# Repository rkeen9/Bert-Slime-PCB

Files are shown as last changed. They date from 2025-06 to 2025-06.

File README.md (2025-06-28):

# Bert-Slime-Tracker
**DOES NOT WORK YET.** If you build this, you will get a non-functional tracker. This repository will be updated once troubleshooting is complete. I'm documenting the troubleshooting here: [Troubleshooting](https://github.com/rkeen9/Bert-Slime-Tracker/blob/main/Troubleshooting/Troubleshooting.md)

Another slime tracker. This one was designed for small form factor and easy DIY that involves minimal soldering and easily obtainable parts. This is essentially just an ICM-45686 breakout board which you can install a D1 mini directly to via 2x8 port 2.54 mm female headers. A TP-4056 charger module can also be installed directly to the board via 2.54mm male headers. Assembly instructions to come once this project is functional.

# Folder Structure 
- **Bert-Slime-Tracker/** Main folder. Contains KiCAD project files and all other folders.
- **Bert-Slime-Tracker/Libraries** Contains all custom symbols and footprints used in this project
- **Bert-Slime-Tracker/assembly-files** Contains all files that would be needed to have this project built by JLCPCB (https://jlcpcb.com/).
- **Bert-Slime-Tracker/Schematics** Contains the schematic in PDF form.
- **Bert-Slime-Tracker/Troubleshooting** Contains my efforts to get this project functional :).

# KiCAD Environment Setup
This project was made in KiCAD 9.0. KiCAD is free PCB design software which can be downloaded from https://www.kicad.org/download/. If you are familiar with KiCAD and Github, all you need to know is that the required files for all custom components are in the **Libraries** folder.

If you're new to KiCAD or need a refresher, the following is step by step instructions for opening this project following a fresh KiCAD install:
1. Download this project through GitHub's **Download Zip** option as shown below and extract it to the desired project location:
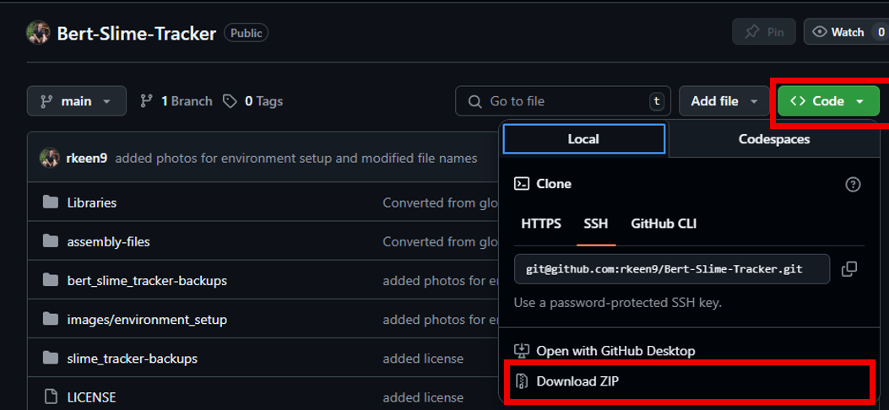
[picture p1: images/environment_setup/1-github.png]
github

2. Run KiCAD and open the **Footprint Editor** from the start screen
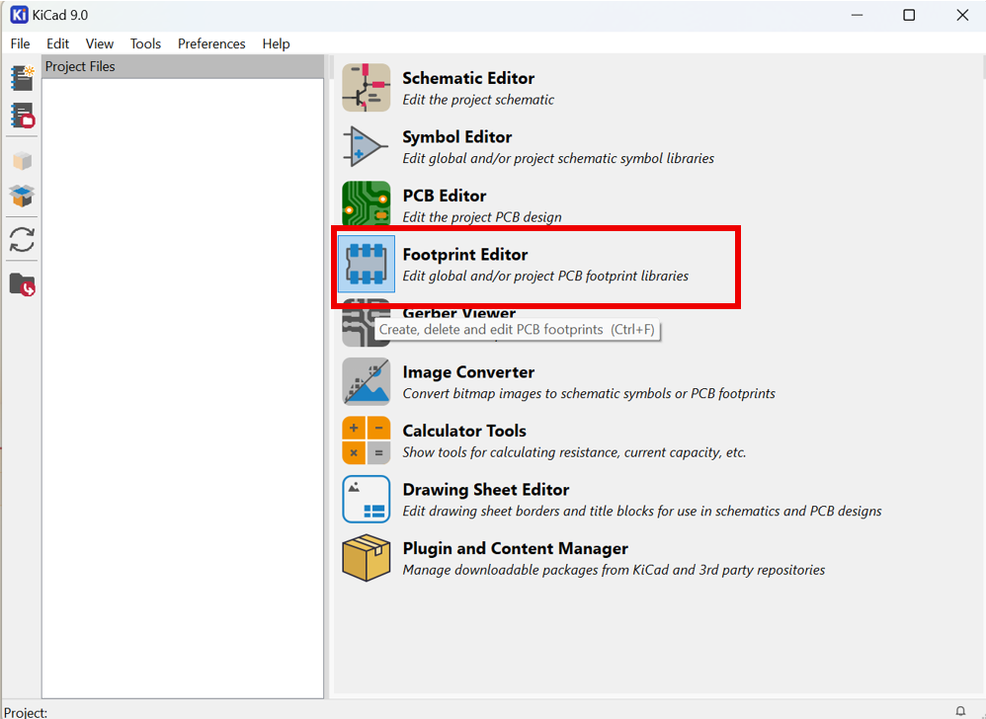
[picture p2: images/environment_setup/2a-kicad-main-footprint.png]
Main Screen

Continue with the default options if this popup appears:
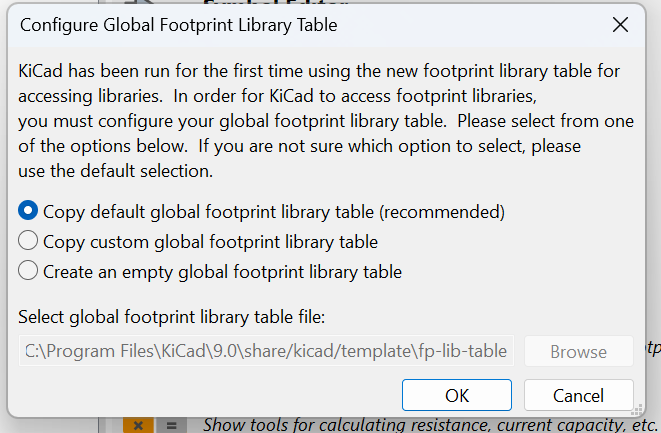
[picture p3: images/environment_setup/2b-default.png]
default

3. From the **Footprint Editor**, Go to **File>Add Library**

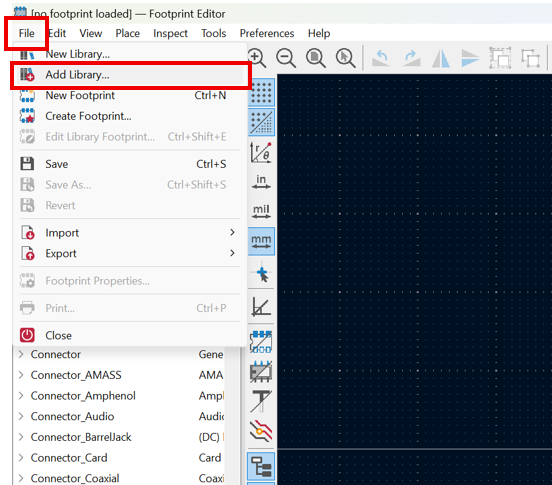
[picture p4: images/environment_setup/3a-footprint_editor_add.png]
footprint


Navigate to where you extracted the project files, select the **Libraries/Bert-Slime-PCB.pretty** folder, and hit **Select Folder**
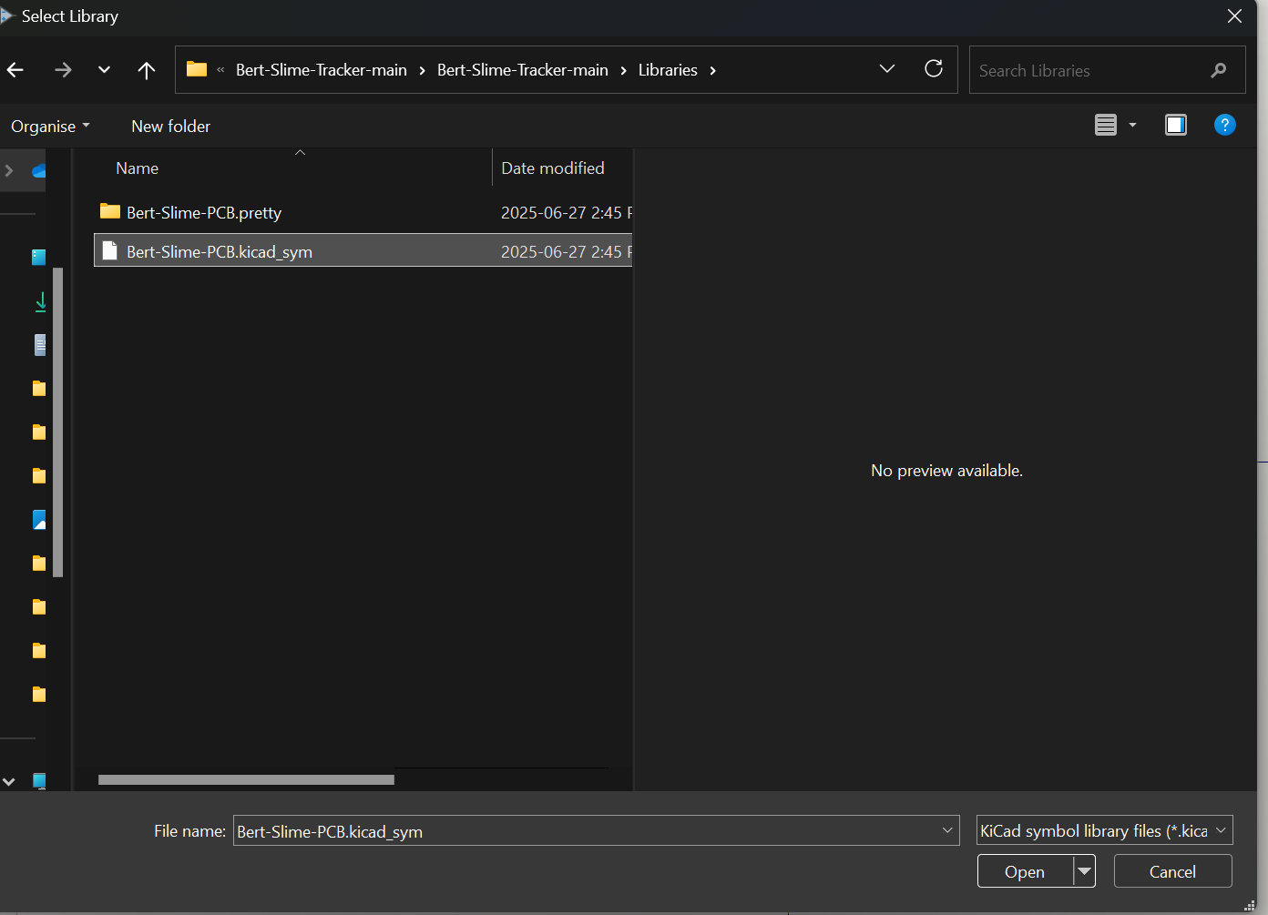
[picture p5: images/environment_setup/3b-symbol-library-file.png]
pretty file


4. Exit from the **Footprint Editor** and open the **Symbol Editor** from the KiCAD start screen
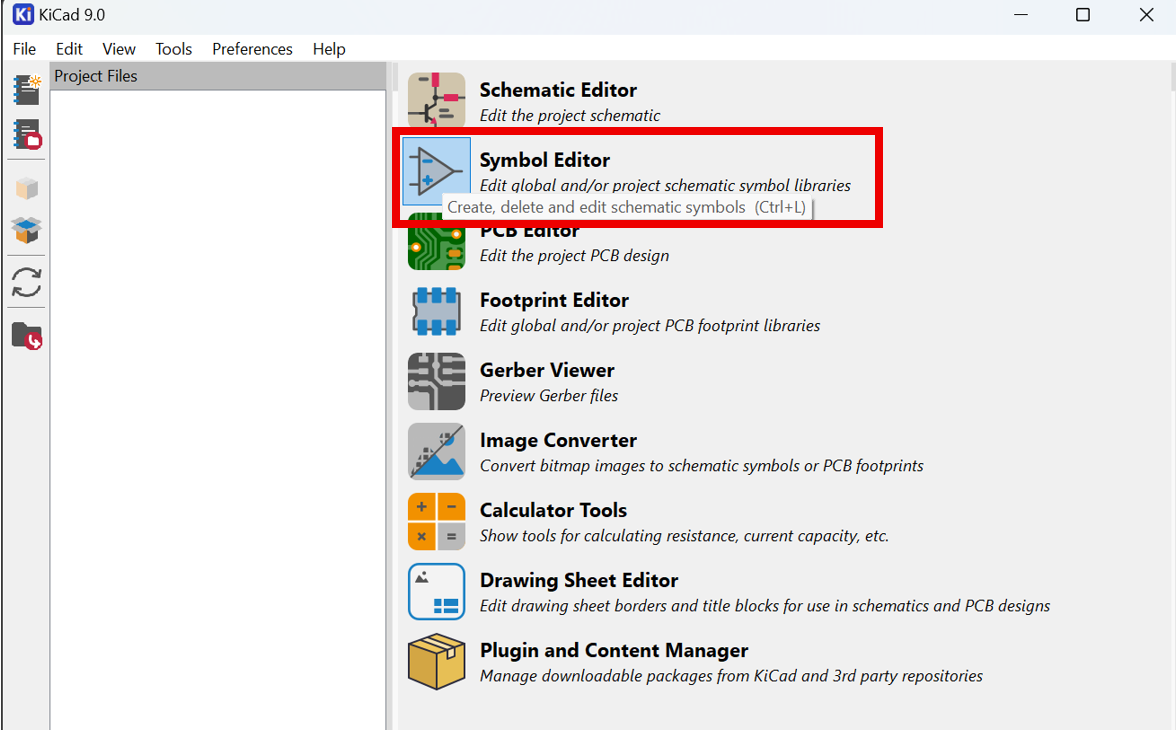
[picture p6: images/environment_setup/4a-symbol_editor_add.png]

Continue with the default options if this popup appears:
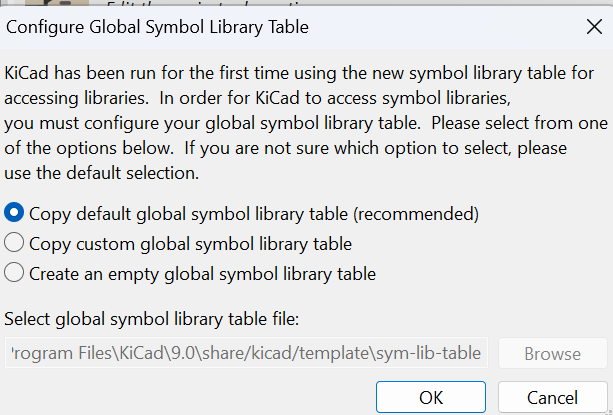
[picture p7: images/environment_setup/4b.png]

5. From the **Symbol Editor**, Go to **File>Add Library**
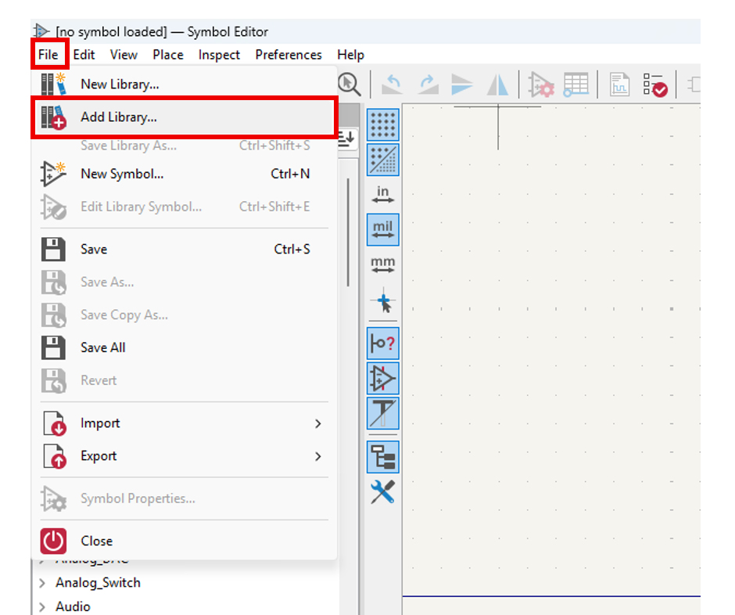
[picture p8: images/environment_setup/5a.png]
Symbol


Navigate to where you extracted the project files and open the **Libraries/Bert-Slime-PCB.kicad_sym** file.
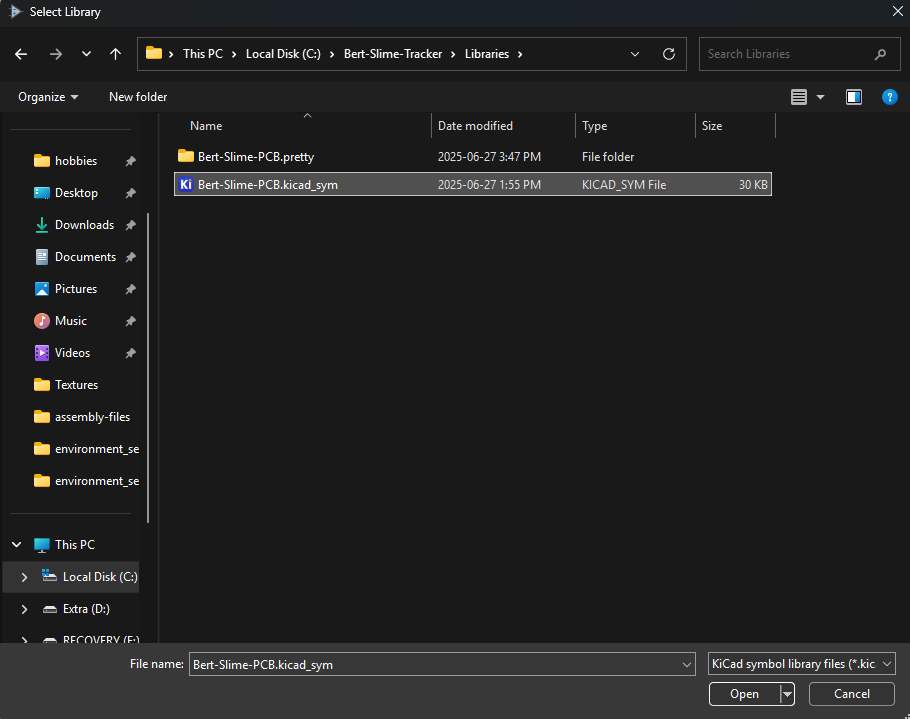
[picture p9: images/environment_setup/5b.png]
Symbol Path


6. Exit from the **Symbol Editor** and open the project from the KiCAD start screen as shown:
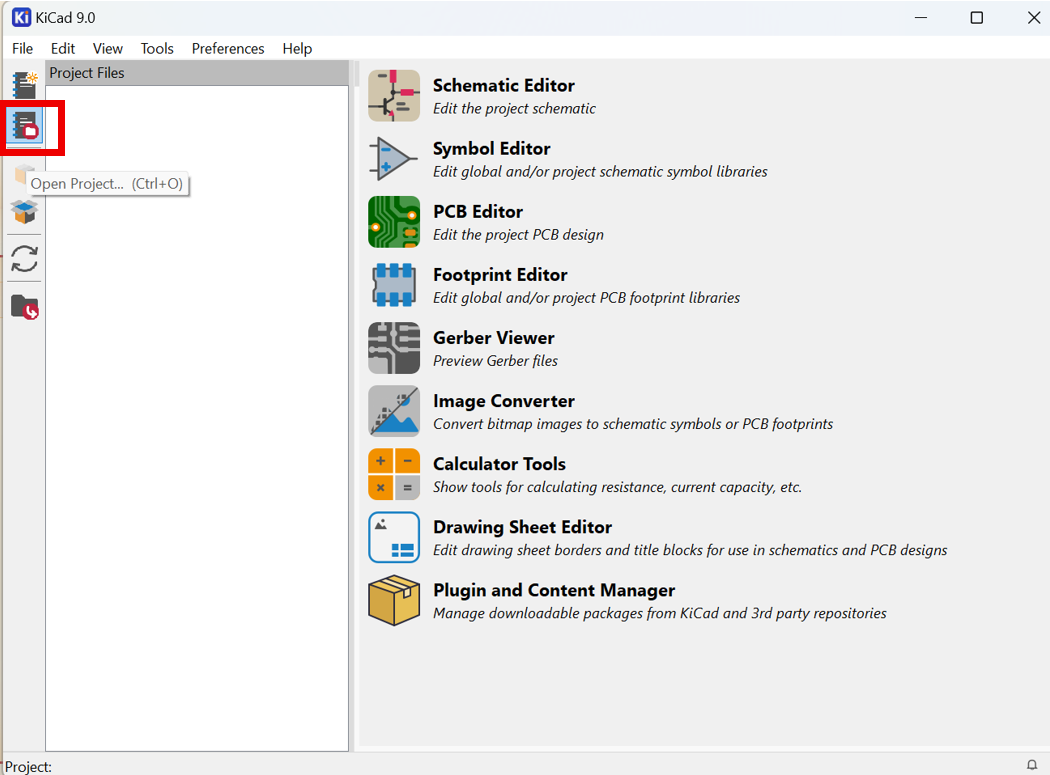
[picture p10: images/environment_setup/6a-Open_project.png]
Open Proj


Now navigate to the project folder and open the **bert_slime_tracker.kicad_pro** file
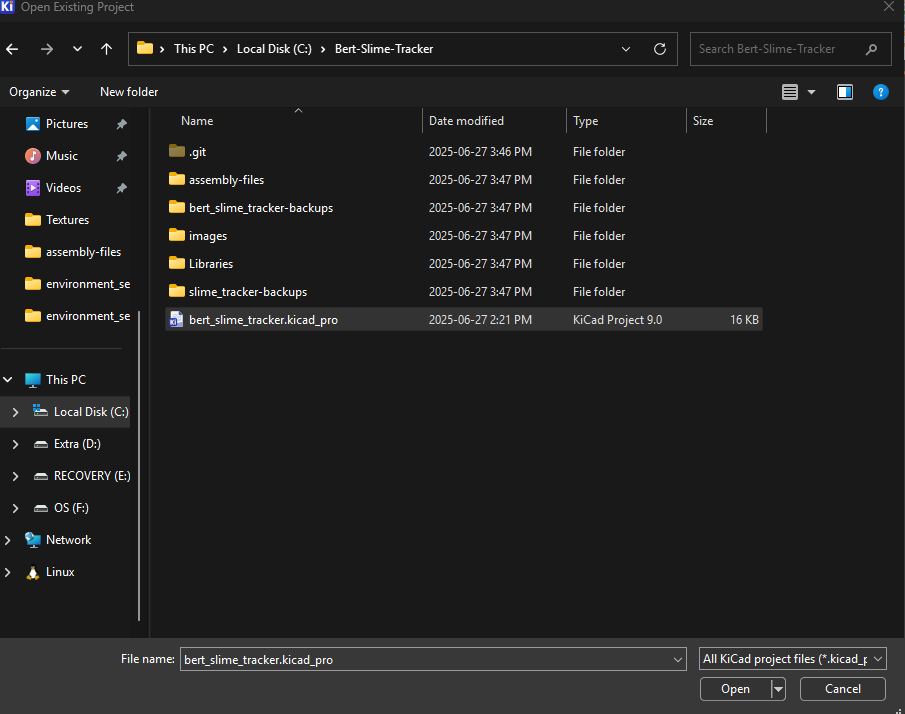
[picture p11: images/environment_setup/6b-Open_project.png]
Open Proj


7. The project can now be edited in KiCAD. the **bert_slime_tracker.kicad_sch** file contains the project schematics and the **slime_tracker.kicad_pcb** file contains the PCB design itself.

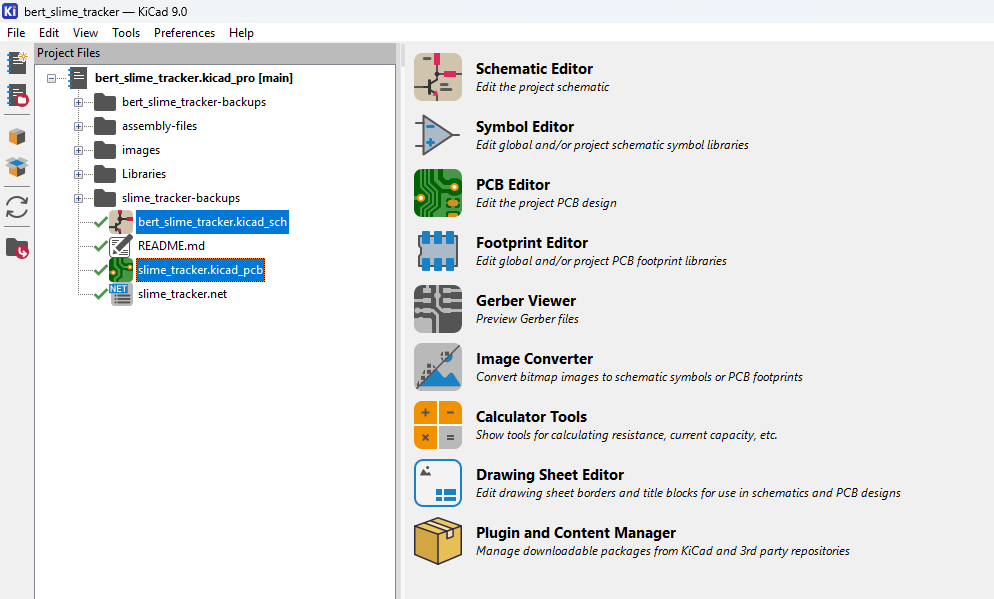
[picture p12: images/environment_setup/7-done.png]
done


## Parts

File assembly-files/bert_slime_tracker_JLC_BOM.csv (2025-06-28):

Designator | JCLPCB Part # | Footprint | Comment
C1,C2 | C1591 | Capacitor_SMD:C_0603_1608Metric | 100nF
C3 | C57895 | Capacitor_SMD:C_0603_1608Metric | 2.2uF
CN1 | C136657 | Bert-Slime-PCB:CONN-SMD_SM05B-SRSS-TB-LF-SN | SM05B-SRSS-TB (LF)(SN)
D1,D2 | C458181 | Bert-Slime-PCB:SOD993_L1.0-W0.6-LS1.0-RD | PMEG3010ESBYL
R1 | C22827 | Resistor_SMD:R_0603_1608Metric_Pad0.98x0.95mm_HandSolder | 180K
R2,R3,R4,R5 | C25804 | Resistor_SMD:R_0603_1608Metric_Pad0.98x0.95mm_HandSolder | 10K
SW1 | C963206 | Bert-Slime-PCB:SW-SMD_MK-12C02-G020 | MK-12C02-G020
U1 | C22459454 | Bert-Slime-PCB:IC_ICM-45686 | ICM-45686
U2 | C5439871 | Bert-Slime-PCB:X1-WLB0808-4_L0.8-W0.8-P0.40-TL | QMC6309
Y1 | C555607 | Crystal:Crystal_SMD_3225-4Pin_3.2x2.5mm | 32.768 kHz Oscillator

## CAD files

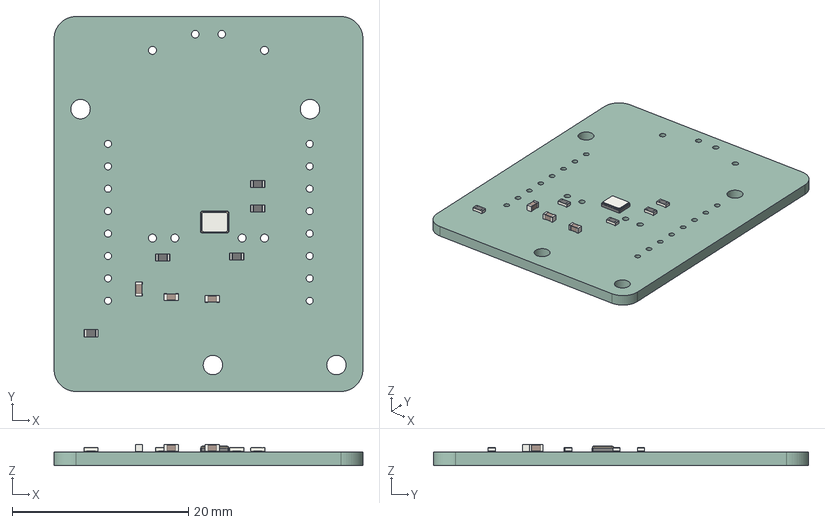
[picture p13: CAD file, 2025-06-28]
bert_slime_tracker.step
35.0 x 42.5 x 2.40 mm
R_0603_1608Metric x 5
C_0603_1608Metric x 3
Crystal_SMD_3225-4Pin_3.2x2.5mm
bert_slime_tracker_PCB

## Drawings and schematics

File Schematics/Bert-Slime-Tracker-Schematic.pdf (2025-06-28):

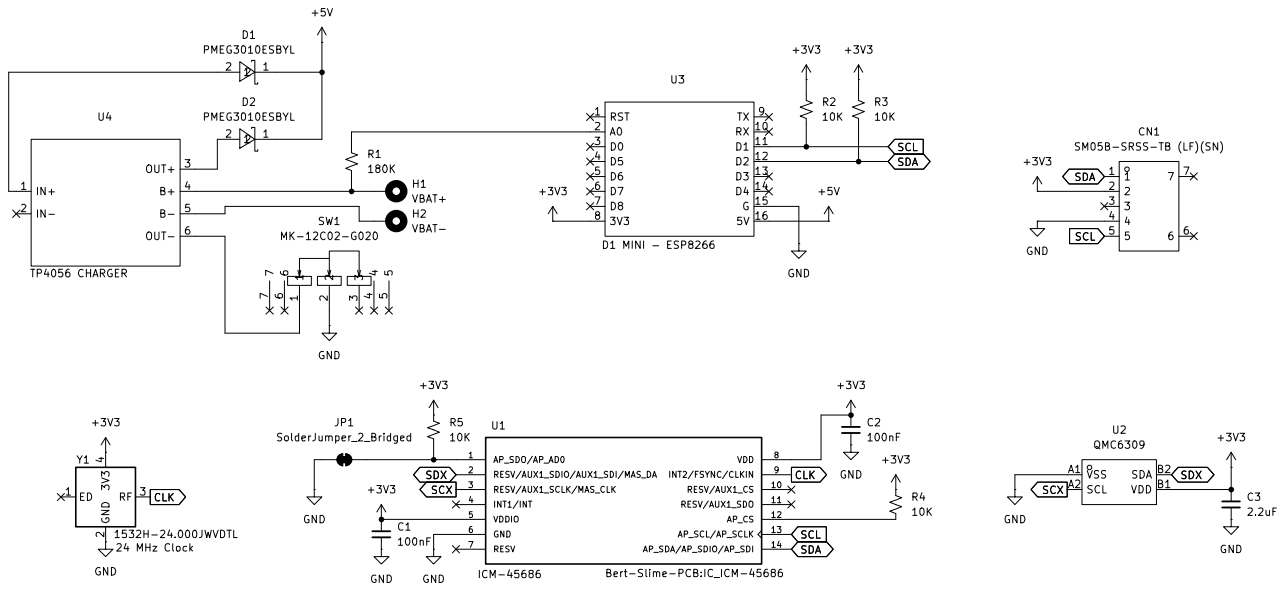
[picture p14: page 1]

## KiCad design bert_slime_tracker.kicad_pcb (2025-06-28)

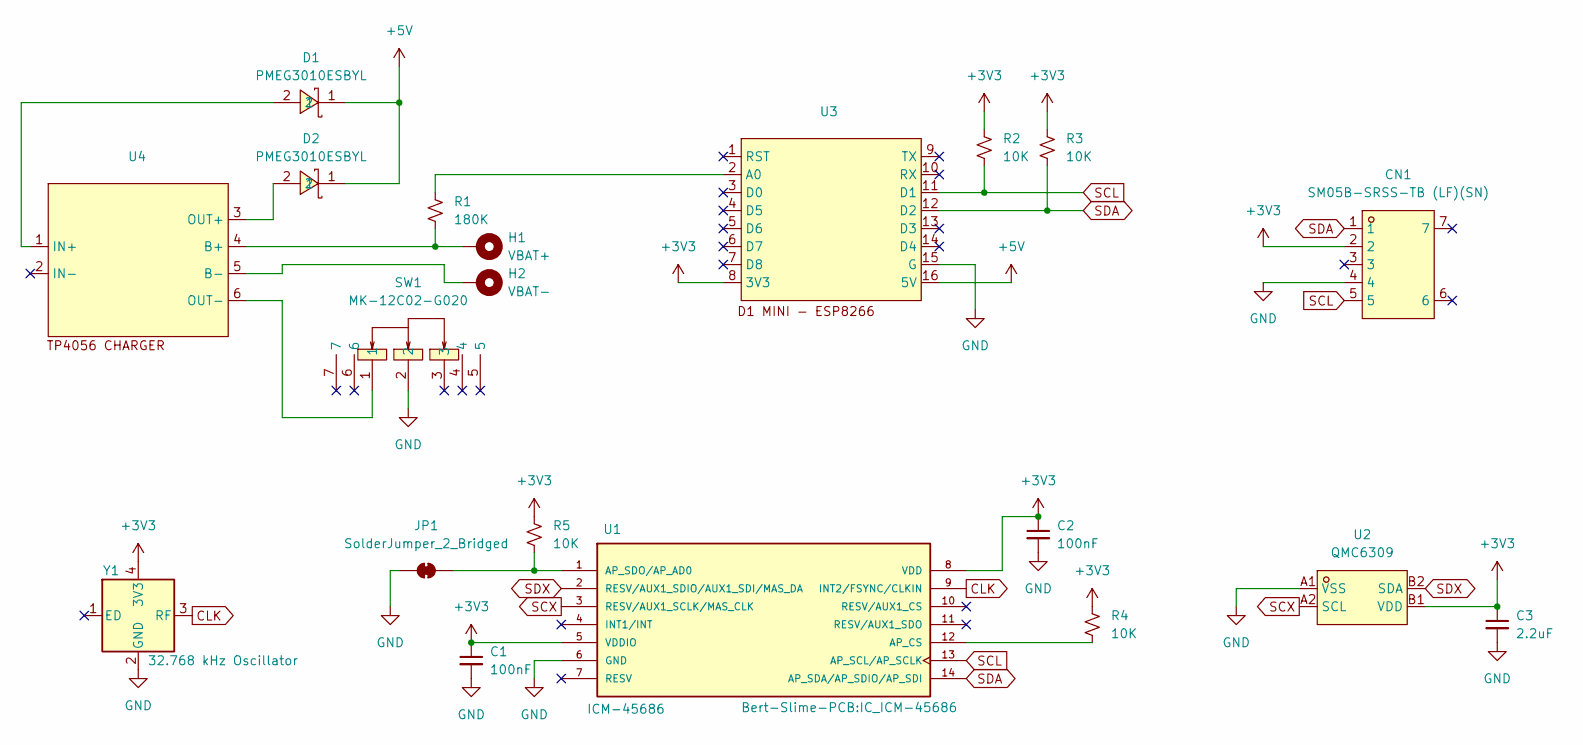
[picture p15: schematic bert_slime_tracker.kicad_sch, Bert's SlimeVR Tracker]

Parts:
C1, C2: 100nF; C_0603_1608Metric; LCSC Part C1591
C3: 2.2uF; C_0603_1608Metric; LCSC Part C57895
CN1: SM05B-SRSS-TB (LF)(SN); CONN-SMD_SM05B-SRSS-TB-LF-SN; LCSC Part C136657
D1, D2: PMEG3010ESBYL; SOD993_L1.0-W0.6-LS1.0-RD; LCSC Part C458181
H1: VBAT+; TestPoint_Pad_2.0x2.0mm
H2: VBAT-; TestPoint_Pad_2.0x2.0mm
JP1: SolderJumper_2_Bridged; SolderJumper-2_P1.3mm_Bridged_Pad1.0x1.5mm
R1: 180K; R_0603_1608Metric_Pad0.98x0.95mm_HandSolder; LCSC Part C22827
R2, R3, R4, R5: 10K; R_0603_1608Metric_Pad0.98x0.95mm_HandSolder; LCSC Part C25804
SW1: MK-12C02-G020; SW-SMD_MK-12C02-G020; LCSC Part C963206
U1: ICM-45686; IC_ICM-45686; PARTREV 0.2; LCSC Part C22459454
U2: QMC6309; X1-WLB0808-4_L0.8-W0.8-P0.40-TL; LCSC Part C5439871
U3: D1-Mini
U4: TP4056-USBC-MODULE
Y1: 32.768 kHz Oscillator; Crystal_SMD_3225-4Pin_3.2x2.5mm; LCSC Part C555607

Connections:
+3V3: C1.1, C2.1, C3.1, CN1.2, R2.1, R3.1, R4.1, R5.1, U1.5 (VDDIO), U1.8 (VDD), U2.B1 (VDD), U3.8 (3V3), Y1.4 (3V3)
+5V: D1.1, D2.1, U3.16 (5V)
CLK: U1.9 (INT2/FSYNC/CLKIN), Y1.3 (RF)
GND: C1.2, C2.2, C3.2, CN1.4, JP1.1 (A), SW1.2, U1.6 (GND), U2.A1 (VSS), U3.15 (G), Y1.2 (GND)
unnamed: JP1.2 (B), R5.2, U1.1 (AP_SDO/AP_AD0)
unnamed: R4.2, U1.12 (AP_CS)
unnamed: R1.2, U3.2 (A0)
unnamed: H1.1, R1.1, U4.4 (B+)
unnamed: H2.1, U4.5 (B-)
unnamed: D1.2, U4.1 (IN+)
unnamed: D2.2, U4.3 (OUT+)
unnamed: SW1.1, U4.6 (OUT-)
SCL: CN1.5, R2.2, U1.13 (AP_SCL/AP_SCLK), U3.11 (D1)
SCX: U1.3 (RESV/AUX1_SCLK/MAS_CLK), U2.A2 (SCL)
SDA: CN1.1, R3.2, U1.14 (AP_SDA/AP_SDIO/AP_SDI), U3.12 (D2)
SDX: U1.2 (RESV/AUX1_SDIO/AUX1_SDI/MAS_DA), U2.B2 (SDA)

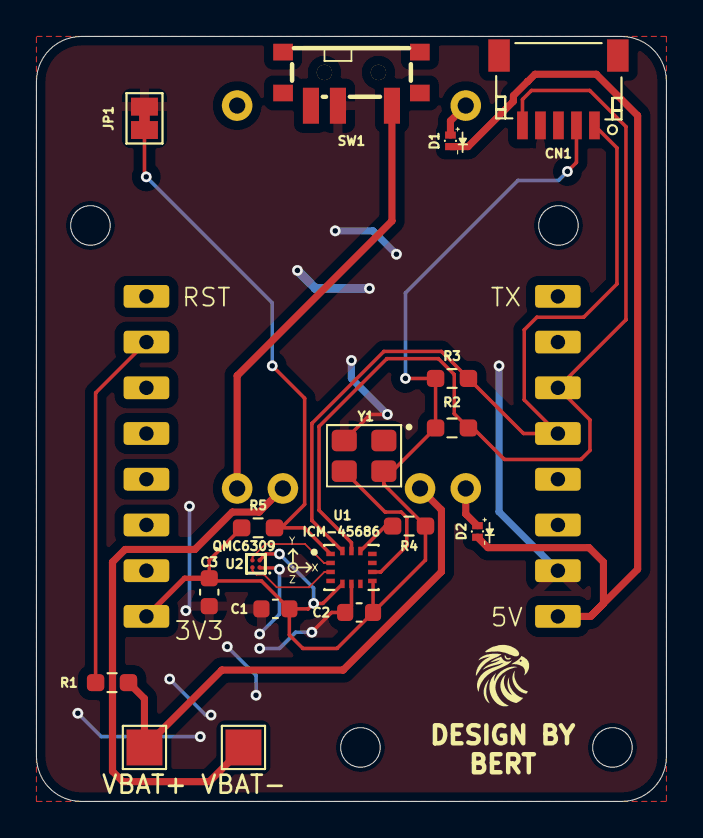
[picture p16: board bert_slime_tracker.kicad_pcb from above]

Board: 2 copper layers, 35.0 x 42.5 mm, 20 parts (0 on the bottom side), 16 nets.

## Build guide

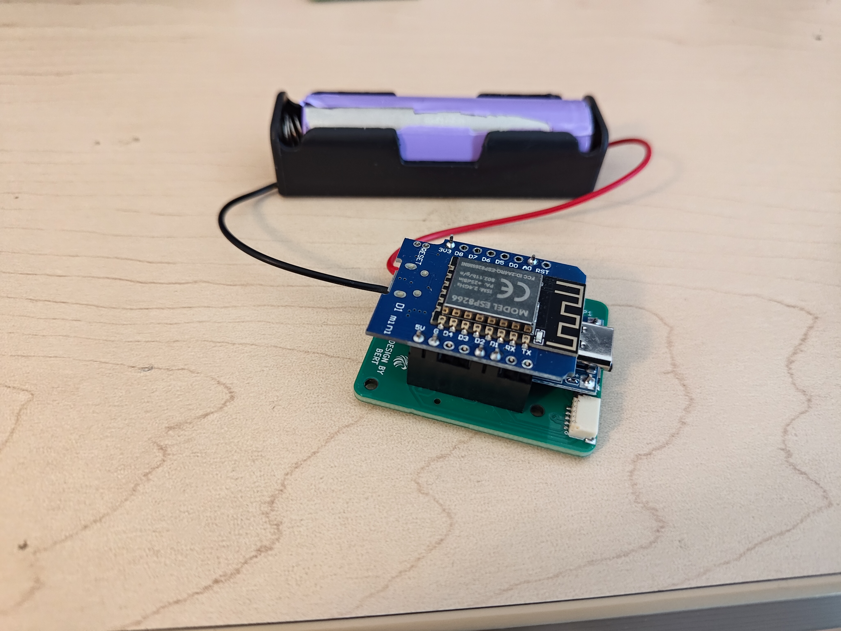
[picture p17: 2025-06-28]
images/Assembled_Electronics.jpg

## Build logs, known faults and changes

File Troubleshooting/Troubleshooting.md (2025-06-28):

# The Current Issue: Trackers Connect But There is no Data

The SlimeVR server is not able to get any orientation data from the ICM-45686. Everything seems to indicate everything is okay except for the lack of data.

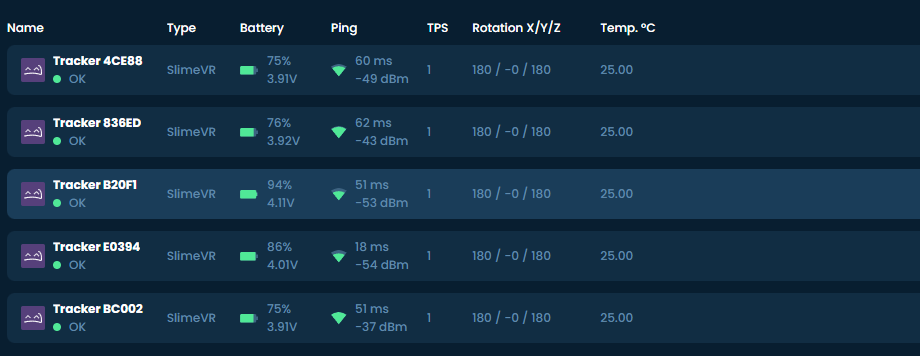
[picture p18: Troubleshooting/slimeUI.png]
Slime UI


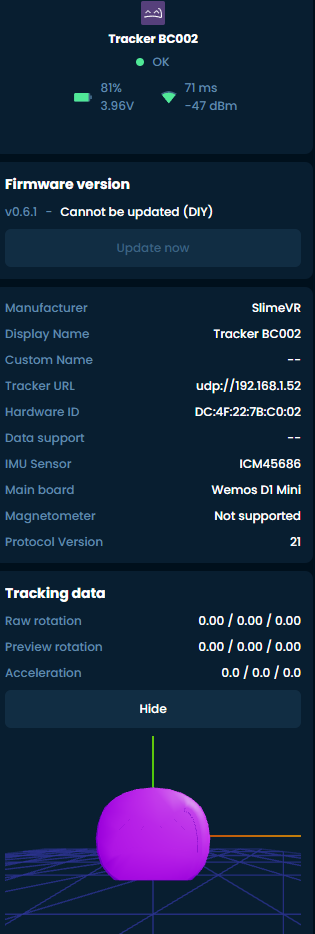
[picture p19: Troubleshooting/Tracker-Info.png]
Device Info|215


When looking in the serial log, all the I2C sensors look to be getting detected as well:

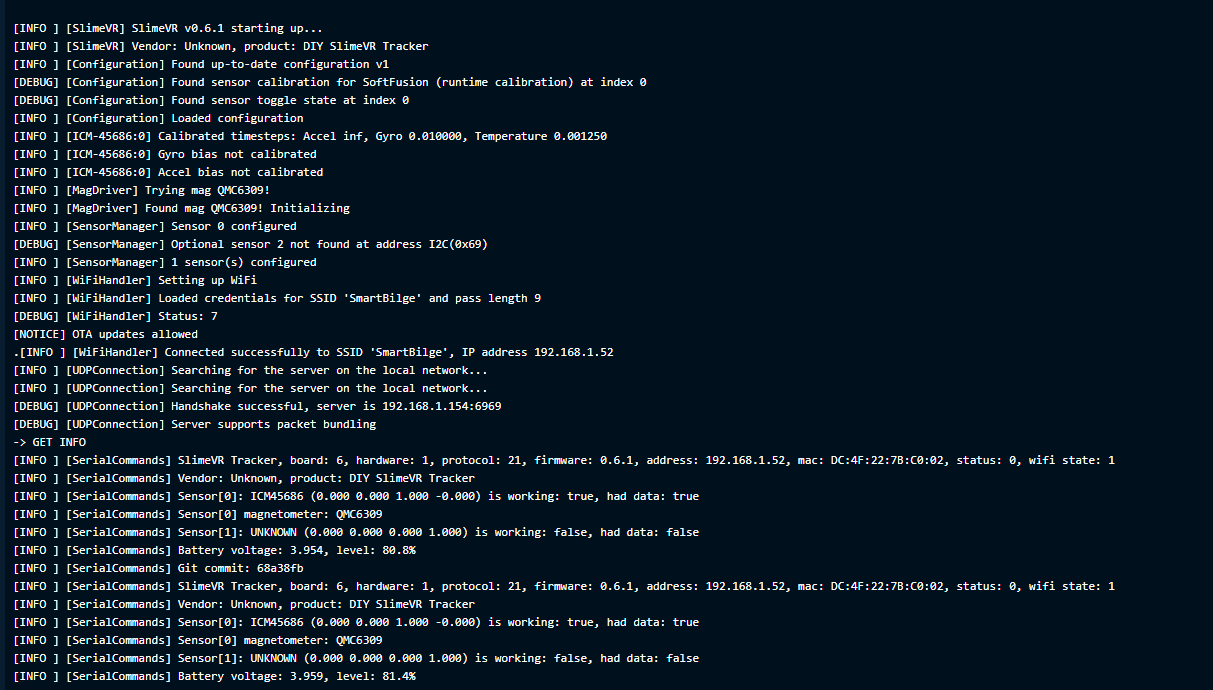
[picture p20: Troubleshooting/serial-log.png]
Serial Log


The "Sensor\[1]" errors I'm assuming are because I don't have a secondary IMU connected.

# Testing

We know that the issue is that the SlimeVR server is not able to receive any data from the ICM-45586. This makes the number one suspect the I2C connection. To isolate this I uploaded some sample code from the ICM45686 Arduino library to my D1 Mini. This code was as follows:

```
#include "ICM45686.h"

// Instantiate an ICM456XX with LSB address set to 0
ICM456xx IMU(Wire,0);

void setup() {
  int ret;
  Serial.begin(115200);
  while(!Serial) {}

  // Initializing the ICM456XX
  ret = IMU.begin();
  if (ret != 0) {
    Serial.print("ICM456xx initialization failed: ");
    Serial.println(ret);
    while(1);
  }
  // Accel ODR = 100 Hz and Full Scale Range = 16G
  IMU.startAccel(100,16);
  // Gyro ODR = 100 Hz and Full Scale Range = 2000 dps
  IMU.startGyro(100,2000);
  // Wait IMU to start
  delay(100);
}

void loop() {

  inv_imu_sensor_data_t imu_data;

  // Read registers
  IMU.getDataFromRegisters(imu_data);

  // Format data for Serial Plotter
  Serial.print("AccelX:");
  Serial.println(imu_data.accel_data[0]);
  Serial.print("AccelY:");
  Serial.println(imu_data.accel_data[1]);
  Serial.print("AccelZ:");
  Serial.println(imu_data.accel_data[2]);
  Serial.print("GyroX:");
  Serial.println(imu_data.gyro_data[0]);
  Serial.print("GyroY:");
  Serial.println(imu_data.gyro_data[1]);
  Serial.print("GyroZ:");
  Serial.println(imu_data.gyro_data[2]);
  Serial.print("Temperature:");
  Serial.println((imu_data.temp_data/128)+25);

  delay(100);
}
```

The only change was modifying the temperature line to get a value is Celsius based on this formula from the datasheet

Temp Formula

This was the result:

Rotation Gif

It is hard to interpret but the data seems right. Rotating about the Y-axis resulted in most of the change being in the GyroY value (orange line). And since these values are angular rotation rate, all of the rotational values went close to 0 when holding the sensor still.

An easier to follow test is shown below. In this test, I only show the temperature reading and briefly hit the sensor with a heat gun set to its lowest setting. 

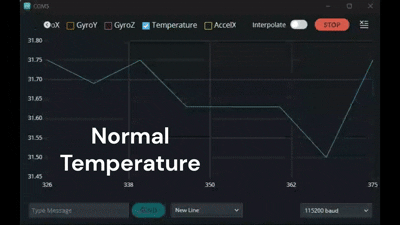
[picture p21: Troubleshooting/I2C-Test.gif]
temp


You can see that the temperature value reacts as expected when heated up and returns as the sensor cools down.

With these results, I'm not sure whether the I2C interface is the issue.

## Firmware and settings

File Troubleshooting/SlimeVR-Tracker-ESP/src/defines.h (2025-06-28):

#define IMU IMU_ICM45686
#define SECOND_IMU IMU
#define BOARD BOARD_WEMOSD1MINI
#define IMU_ROTATION DEG_180
#define SECOND_IMU_ROTATION DEG_0

#define PRIMARY_IMU_OPTIONAL false
#define SECONDARY_IMU_OPTIONAL true

#define MAX_IMU_COUNT 1

#ifndef IMU_DESC_LIST
#define IMU_DESC_LIST \
    IMU_DESC_ENTRY(IMU,        PRIMARY_IMU_ADDRESS_ONE,   IMU_ROTATION,        PIN_IMU_SCL, PIN_IMU_SDA, PRIMARY_IMU_OPTIONAL,   PIN_IMU_INT) 

#endif

// Battery monitoring options (comment to disable):
// BAT_EXTERNAL for ADC pin, BAT_INTERNAL for internal - can detect only low battery, BAT_MCP3021 for external ADC
#define BATTERY_MONITOR BAT_EXTERNAL
#define BATTERY_SHIELD_RESISTANCE 180 //130k BatteryShield, 180k SlimeVR or fill in external resistor value in kOhm

#define PIN_IMU_SDA D2
#define PIN_IMU_SCL D1
#define PIN_IMU_INT D5
#define PIN_IMU_INT_2 D6
#define PIN_BATTERY_LEVEL A0

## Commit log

2025-06-27 Converted from global to project libraries
    [Bert-Slime-PCB-JLC-BOM.csv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]
2025-06-27 added photos for environment setup and modified file names
    [bert_slime_tracker.kicad_sch]
2025-06-28 added schematic files
    [bert_slime_tracker.kicad_pcb, bert_slime_tracker.kicad_sch]
2025-06-28 added some images and a troubleshooting folder
    [Configuration.h]
2025-06-28 updated to corrected oscillator
    [bert_slime_tracker-B_Cu.gbl, bert_slime_tracker-B_Mask.gbs, bert_slime_tracker-B_Paste.gbp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]
